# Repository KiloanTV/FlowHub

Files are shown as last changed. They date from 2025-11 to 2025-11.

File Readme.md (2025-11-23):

<div>
  <h1 align="center">FlowHub V1</h1>

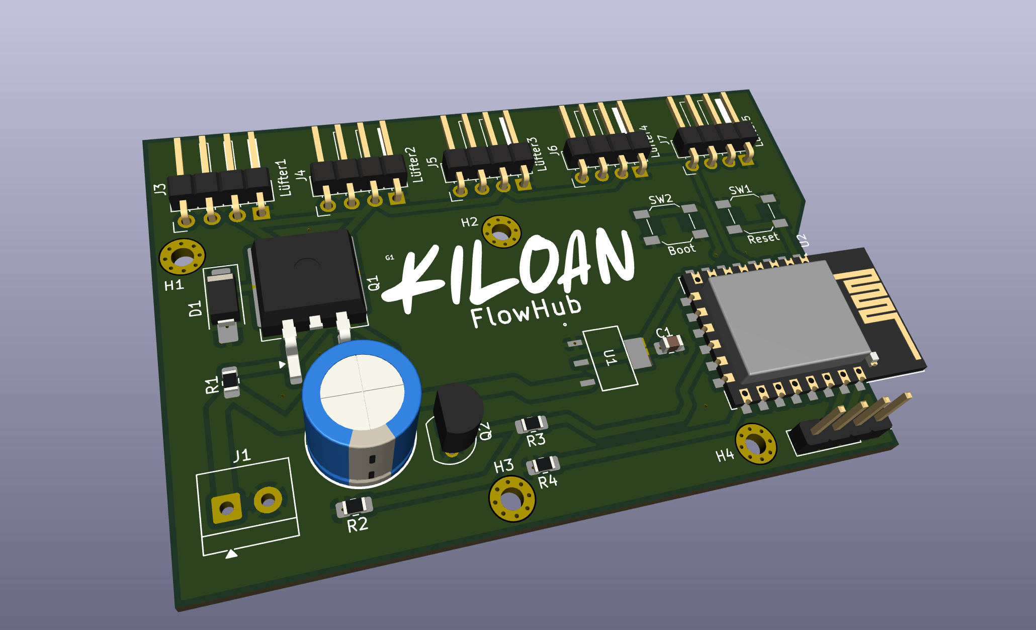
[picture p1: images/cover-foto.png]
FlowHub
  

  <p align="center">
  <a href="https://blueprint.hackclub.com/">
    
  </a>
  </p>
  <h1></h1>
  <p align="center">
    ESP8266-based PC fan controller for Racks.
  </p>
</div>

<sub align="center">This work is licensed under the
[MIT License](https://mit-license.org).
</sub>

## Table of Contents

- [About](#about)
- [Pictures](#pictures)
- [Bill of Materials](#bill-of-materials)

# About

So I had the idea to develop a central control unit for PC fans, more precisely, one for a mobile rack that also houses computers. Then I could control the fan speeds independently of the individual computers. As I said, I needed this for my rack, which I used for learning and experimenting, so I built a simple PCB with a case for this purpose.

# Pictures

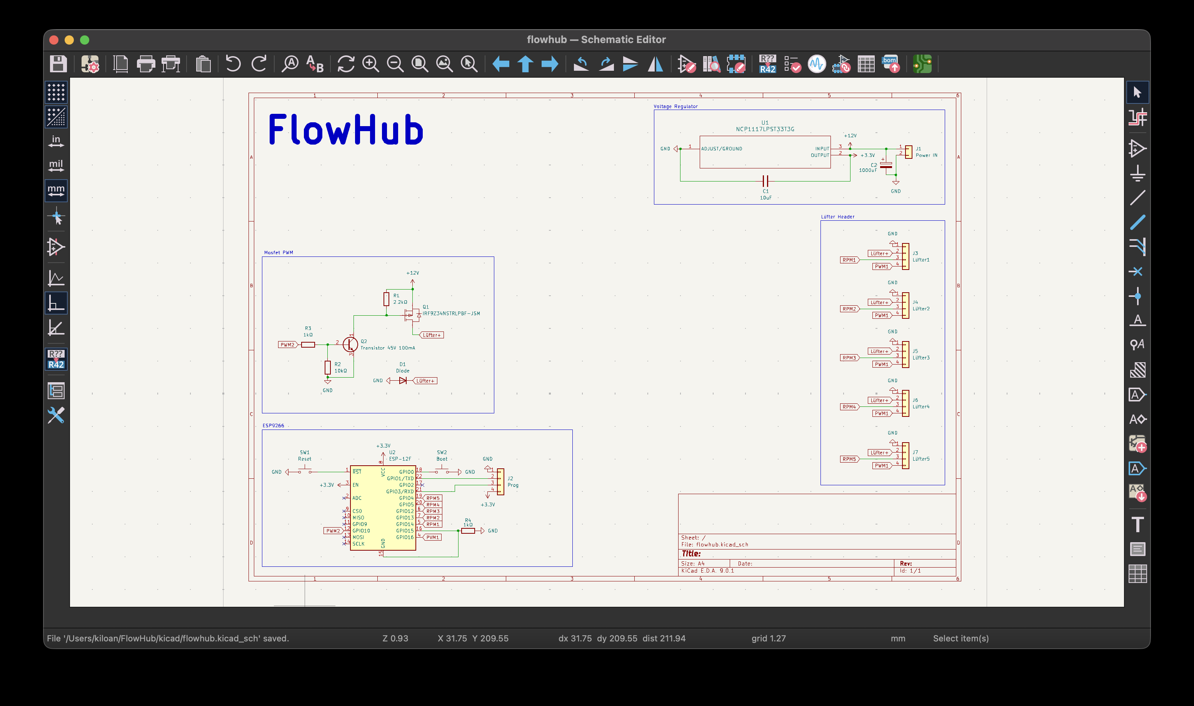
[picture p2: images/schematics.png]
schematics


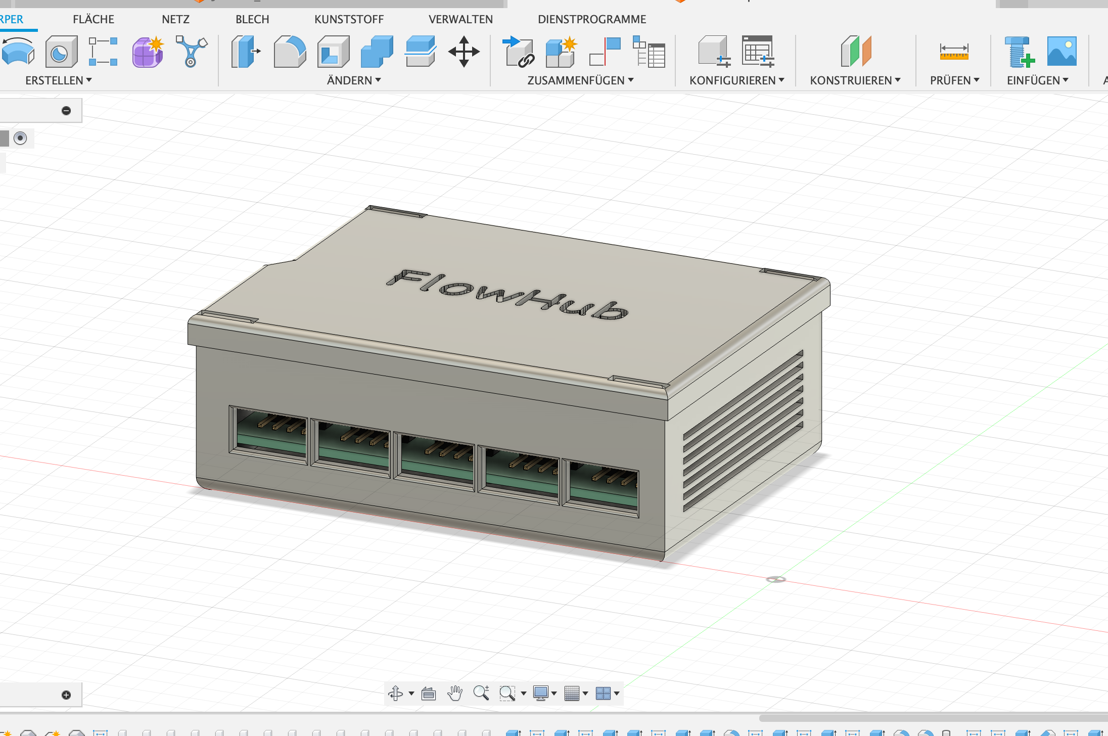
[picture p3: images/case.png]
pcb


# Bill of Materials

<details>
<summary><strong>Show Bill Of Materials(BOM) ----></strong></summary>

|Designator|Footprint |Quantity|Value |LCSC Part #|
|---|---|---|---|---|
|C1 |0805 |1 |10uF |C2897295 |
|C2 |CP_Radial_D10.0mm_P5.00mm |1 |1000uF |C10750 |
|D1 |D_SMA_Handsoldering |1 |Diode |C22452 |
|J1 |TerminalBlock_4Ucon_1x02_P3.50mm_Horizontal|1 |Power IN |C695629 |
|J2 |PinHeader_1x04_P2.54mm_Vertical |1 |Prog |C52016392  |
|J3 |PinHeader_1x04_P2.54mm_pclüfter |1 |Lüfter1 |C722747 |
|J4 |PinHeader_1x04_P2.54mm_pclüfter |1 |Lüfter2 |C722747 |
|J5 |PinHeader_1x04_P2.54mm_pclüfter |1 |Lüfter3 |C722747 |
|J6 |PinHeader_1x04_P2.54mm_pclüfter |1 |Lüfter4 |C722747 |
|J7 |PinHeader_1x04_P2.54mm_pclüfter |1 |Lüfter5 |C722747 |
|Q1 |TO-263-2 |1 |IRF9Z34NSTRLPBF-JSM |C21714355  |
|Q2 |TO-92 |1 |Transistor 45V 100mA|C900800 |
|R1 |0805 |1 |2.2kΩ |C17520 |
|R2 |0805 |1 |10kΩ |C84376 |
|R3, R4 |0805 |2 |1kΩ |C95781 |
|SW1 |SW_SPST_SKQG_WithStem |1 |Reset |C116647 |
|SW2 |SW_SPST_SKQG_WithStem |1 |Boot |C116647 |
|U1 |SOT223-3_ONS |1 |NCP1117LPST33T3G |C146799 |
|U2 |ESP-12E |1 |ESP-12F |C82891 |
|Quote from LCSC: $21.43 Quote from JLCPCB: $28,68 | | | | |

</details>

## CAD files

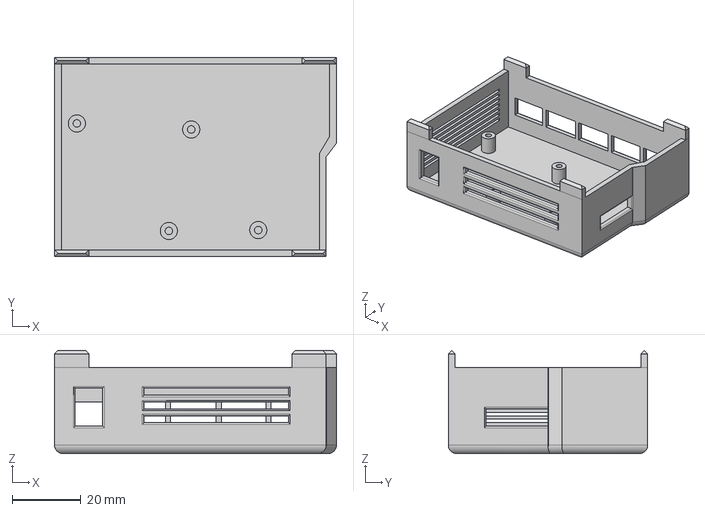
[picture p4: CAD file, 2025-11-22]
cad/case-3dprinting/case-down.step
82.0 x 58.0 x 30.0 mm

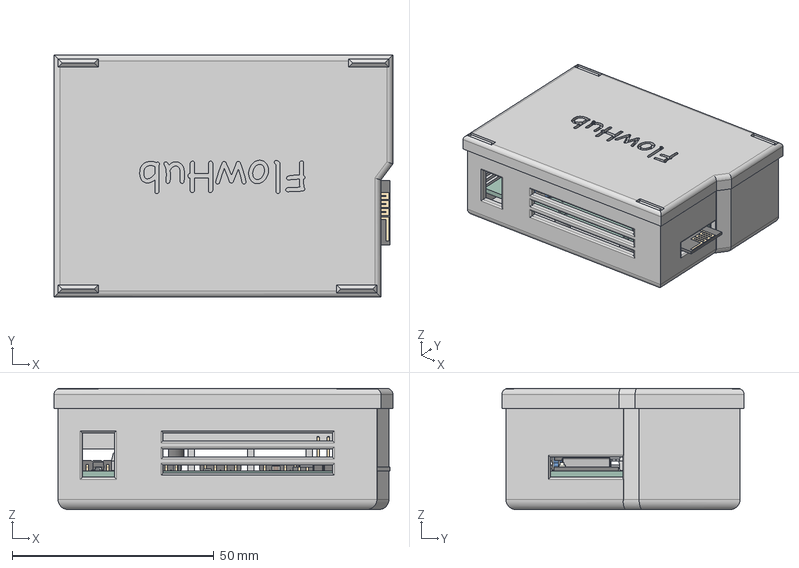
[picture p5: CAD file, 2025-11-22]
cad/flowhub-pcb-case.step
84.0 x 60.0 x 30.0 mm
TO-92
PinHeader_1x04_P2.54mm_Vertical
CP_Radial_D10.0mm_P5.00mm
PinHeader_1x04_P2.54mm_Horizontal x 5
C_0805_2012Metric
R_0805_2012Metric x 4
ESP-12E
flowhub-pcb 1.5.1
D_SMA
case-unten

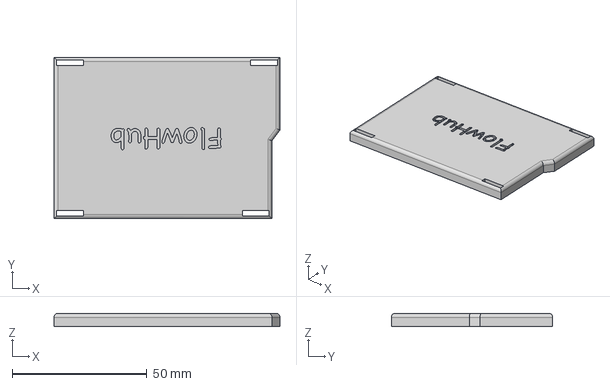
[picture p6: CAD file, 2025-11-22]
cad/case-3dprinting/case-top.step
84.0 x 60.0 x 5.00 mm

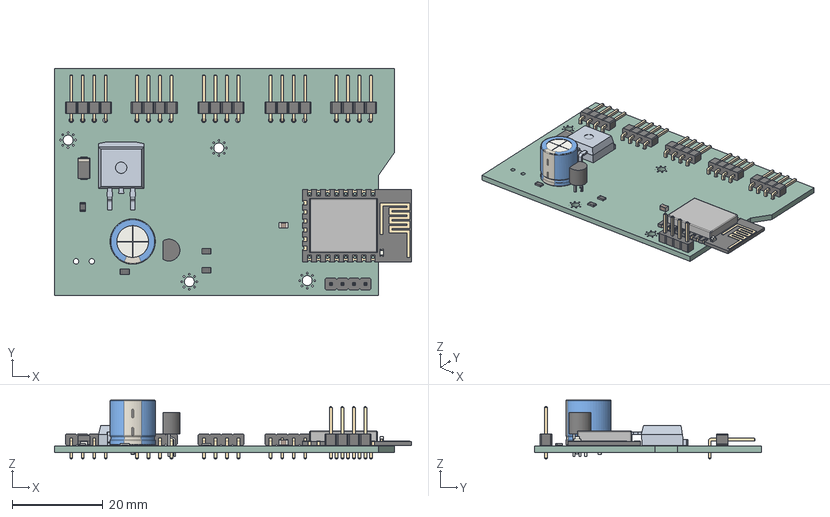
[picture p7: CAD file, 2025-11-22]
cad/flowhub-pcb.step
78.8 x 50.0 x 13.0 mm
PinHeader_1x04_P2.54mm_Horizontal x 5
D_SMA
R_0805_2012Metric x 4
flowhub-pcb 1.5.1
ESP-12E
C_0805_2012Metric
CP_Radial_D10.0mm_P5.00mm
PinHeader_1x04_P2.54mm_Vertical
TO-92
flowhub_PCB

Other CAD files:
cad/flowhub-pcb-case.f3d

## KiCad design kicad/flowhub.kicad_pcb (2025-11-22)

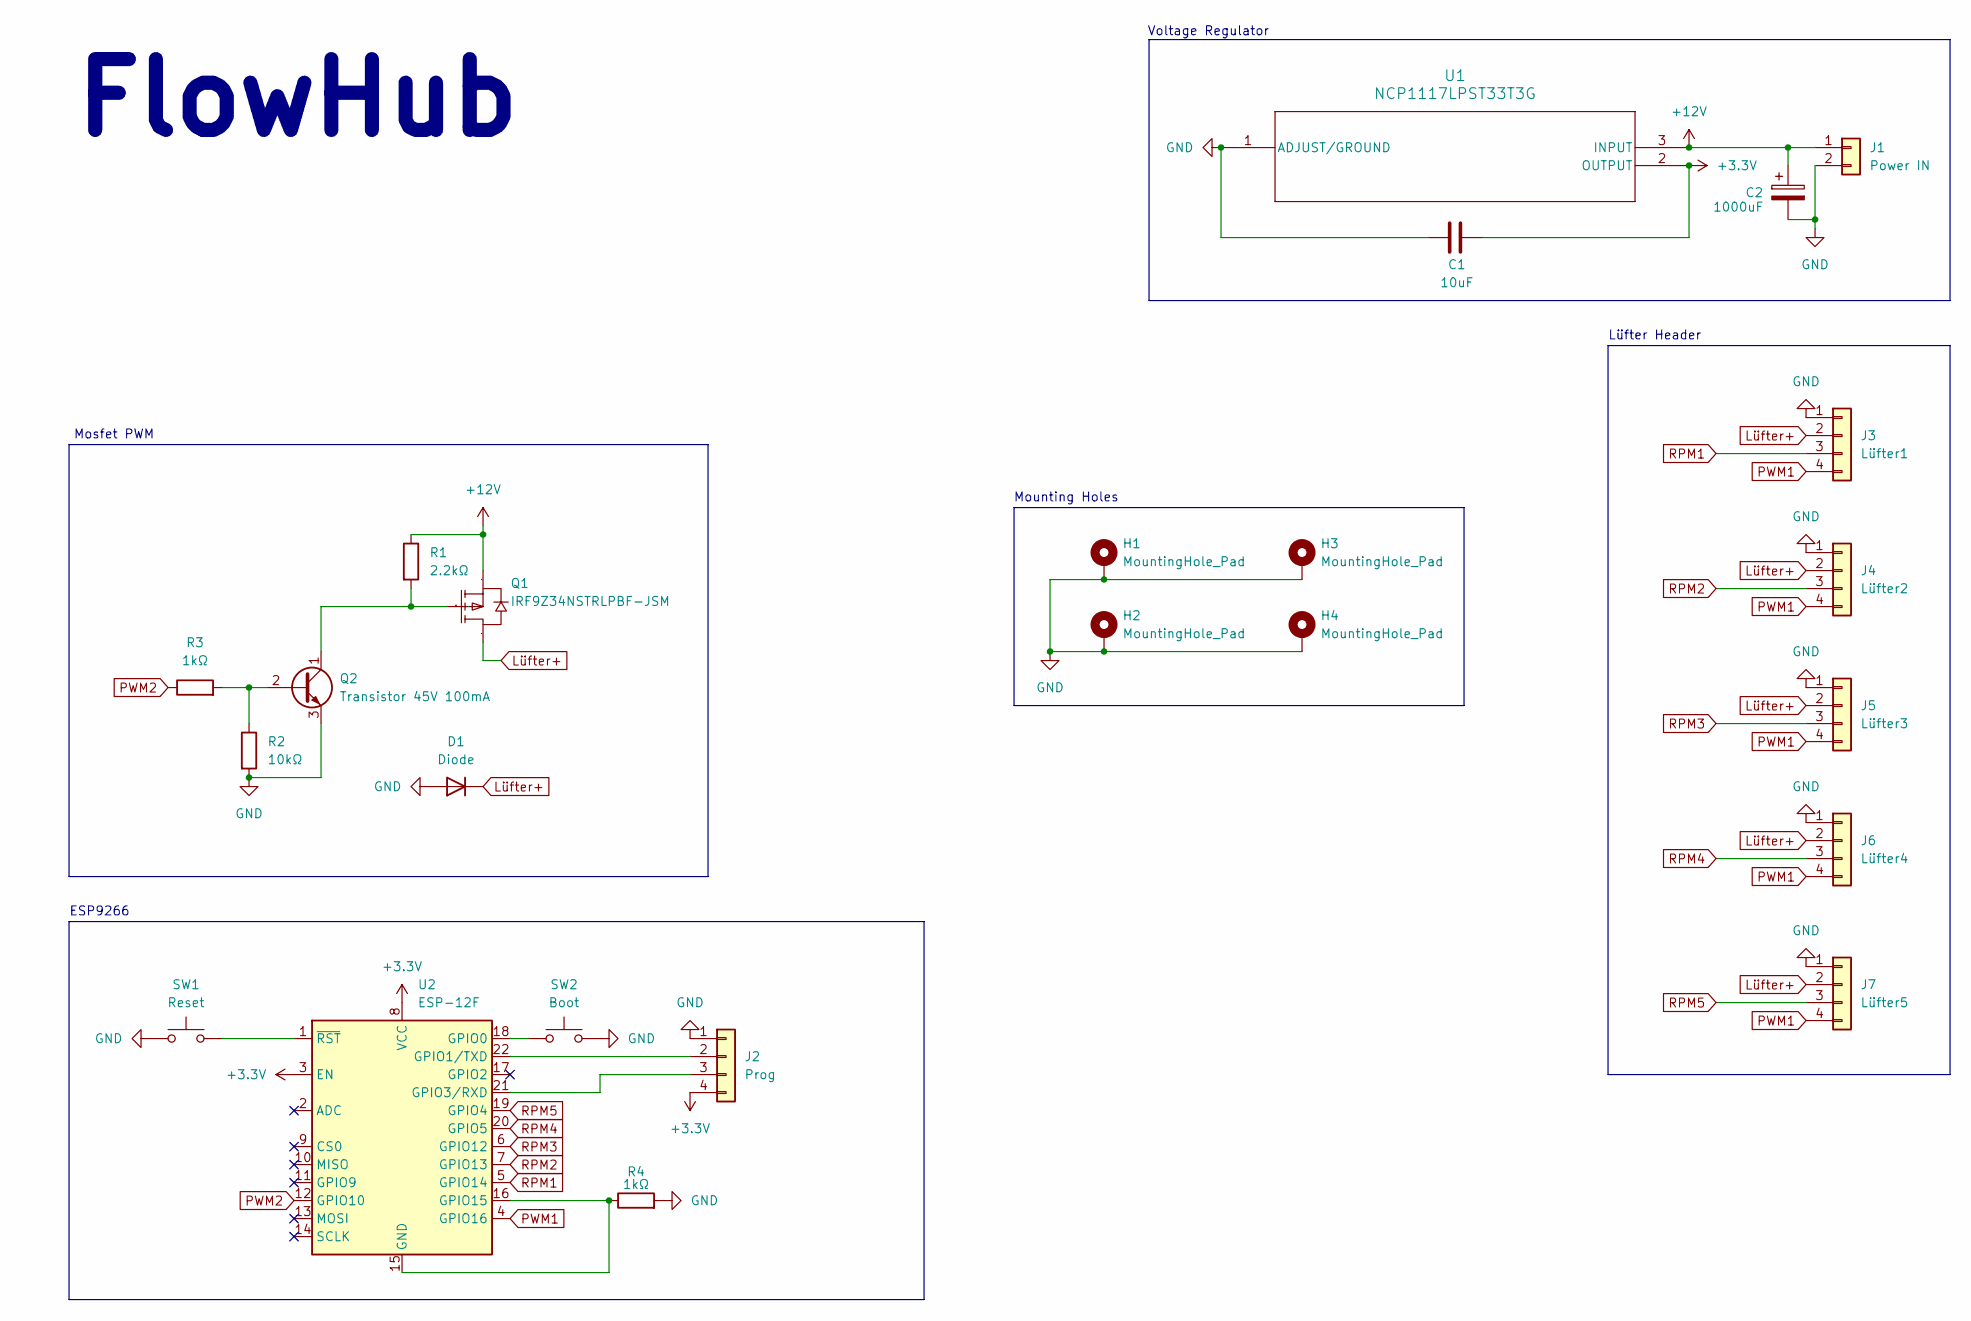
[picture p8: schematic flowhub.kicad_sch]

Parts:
C1: 10uF; C_0805_2012Metric_Pad1.18x1.45mm_HandSolder; LCSC C2897295
C2: 1000uF; CP_Radial_D10.0mm_P5.00mm; LCSC C10750
D1: Diode; D_SMA_Handsoldering; LCSC C22452
H1, H2, H3, H4: MountingHole_Pad; MountingHole_2.2mm_M2_Pad_Via
J1: Power IN; TerminalBlock_4Ucon_1x02_P3.50mm_Horizontal; LCSC C695629
J2: Prog; PinHeader_1x04_P2.54mm_Vertical; LCSC C52016392
J3: Lüfter1; PinHeader_1x04_P2.54mm_pclüfter; LCSC C722747
J4: Lüfter2; PinHeader_1x04_P2.54mm_pclüfter; LCSC C722747
J5: Lüfter3; PinHeader_1x04_P2.54mm_pclüfter; LCSC C722747
J6: Lüfter4; PinHeader_1x04_P2.54mm_pclüfter; LCSC C722747
J7: Lüfter5; PinHeader_1x04_P2.54mm_pclüfter; LCSC C722747
Q1: IRF9Z34NSTRLPBF-JSM; TO-263-2; LCSC C21714355
Q2: Transistor 45V 100mA; TO-92; LCSC C900800
R1: 2.2kΩ; R_0805_2012Metric_Pad1.20x1.40mm_HandSolder; LCSC C17520
R2: 10kΩ; R_0805_2012Metric_Pad1.20x1.40mm_HandSolder; LCSC C84376
R3, R4: 1kΩ; R_0805_2012Metric_Pad1.20x1.40mm_HandSolder; LCSC C95781
SW1: Reset; SW_SPST_SKQG_WithStem; LCSC C116647
SW2: Boot; SW_SPST_SKQG_WithStem; LCSC C116647
U1: NCP1117LPST33T3G; SOT223-3_ONS; LCSC C146799
U2: ESP-12F; ESP-12E; LCSC C82891

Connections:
+3.3V: C1.1, J2.4, U1.2 (OUTPUT), U2.3 (EN), U2.8 (VCC)
+12V: C2.1, J1.1, Q1.3, R1.1, U1.3 (INPUT)
GND: C1.2, C2.2, D1.2 (A), H1.1, H2.1, H3.1, H4.1, J1.2, J2.1, J3.1, J4.1, J5.1, J6.1, J7.1, Q2.3 (C), R2.2, R4.2, SW1.1, SW2.2, U1.1 (ADJUST/GROUND)
Lüfter+: D1.1 (K), J3.2, J4.2, J5.2, J6.2, J7.2, Q1.2
unnamed: J2.2, U2.22 (GPIO1/TXD)
unnamed: J2.3, U2.21 (GPIO3/RXD)
unnamed: Q2.2 (B), R2.1, R3.2
unnamed: Q1.1, Q2.1 (E), R1.2
unnamed: R4.1, U2.15 (GND), U2.16 (GPIO15)
unnamed: SW2.1, U2.18 (GPIO0)
unnamed: SW1.2, U2.1 (~RST)
PWM1: J3.4, J4.4, J5.4, J6.4, J7.4, U2.4 (GPIO16)
PWM2: R3.1, U2.12 (GPIO10)
RPM1: J3.3, U2.5 (GPIO14)
RPM2: J4.3, U2.7 (GPIO13)
RPM3: J5.3, U2.6 (GPIO12)
RPM4: J6.3, U2.20 (GPIO5)
RPM5: J7.3, U2.19 (GPIO4)

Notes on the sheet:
Mosfet PWM
Voltage Regulator
ESP9266
Lüfter Header
FlowHub
Mounting Holes

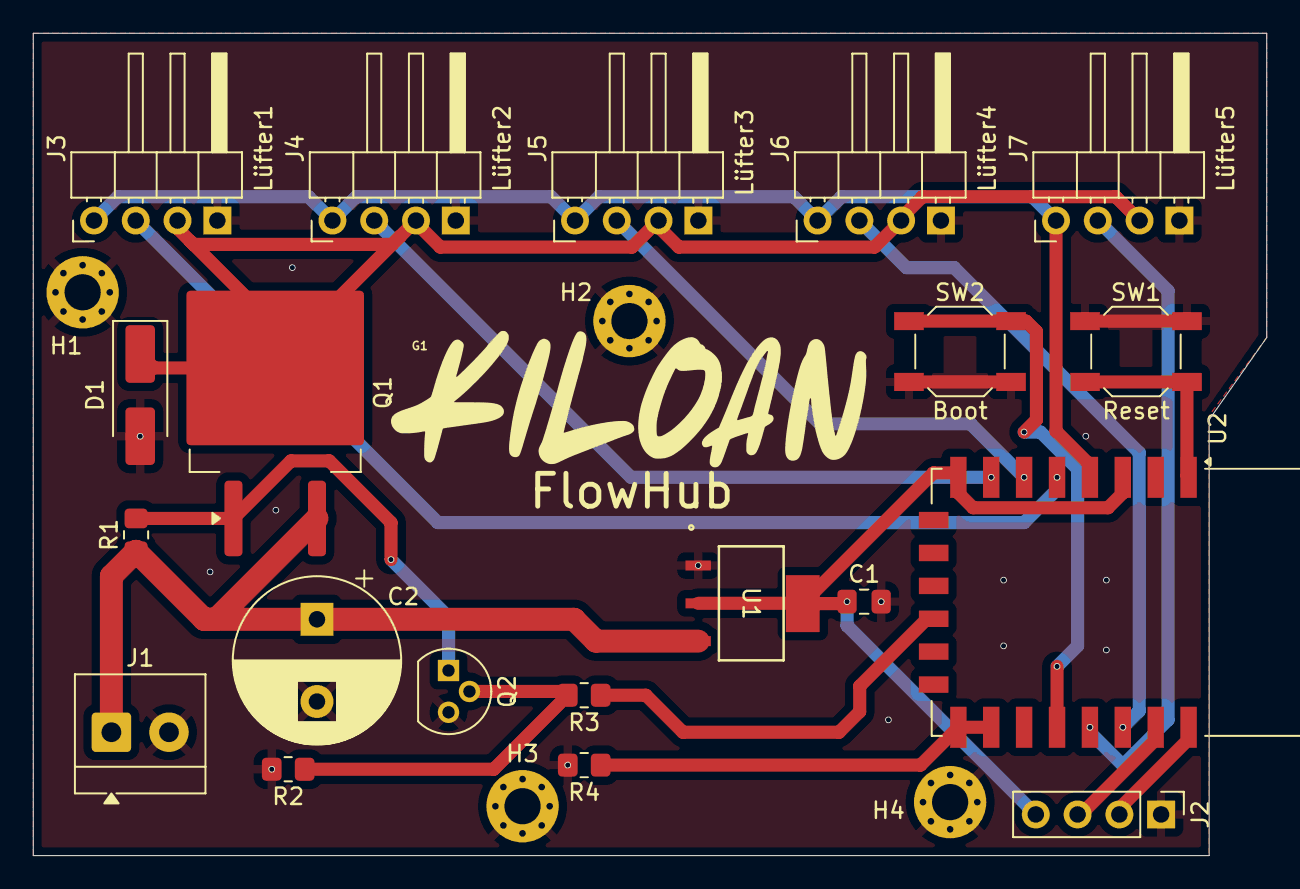
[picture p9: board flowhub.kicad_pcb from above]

Board: 2 copper layers, 75.0 x 50.0 mm, 25 parts (0 on the bottom side), 18 nets.

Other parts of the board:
G1: LOGO
